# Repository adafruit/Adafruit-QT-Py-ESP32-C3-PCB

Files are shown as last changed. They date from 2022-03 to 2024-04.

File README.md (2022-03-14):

## Adafruit QT Py ESP32-C3 WiFi Dev Board with STEMMA QT PCB

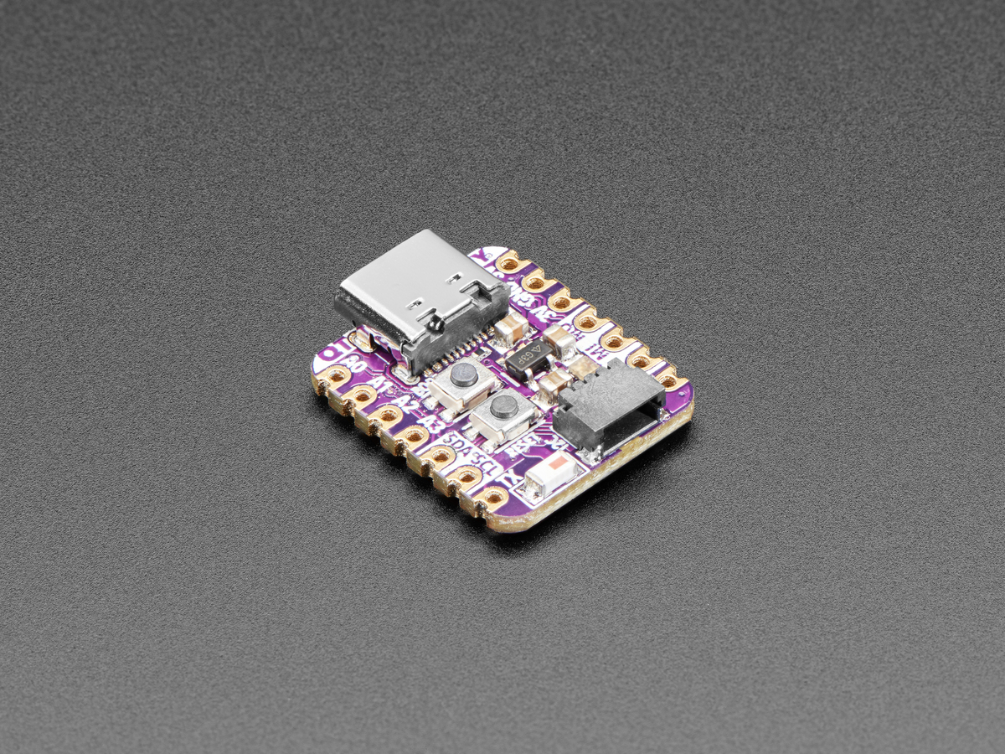
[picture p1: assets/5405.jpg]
<a href="http://www.adafruit.com/products/5405"><br/>
Click here to purchase one from the Adafruit shop</a>

PCB files for the Adafruit QT Py ESP32-C3 WiFi Dev Board with STEMMA QT. 

Format is EagleCAD schematic and board layout
* https://www.adafruit.com/product/5405

### Description

What's life without a little RISC? This miniature dev board is perfect for small projects: it comes with our favorite connector - the STEMMA QT, a chainable I2C port, WiFi, Bluetooth LE, and plenty of FLASH and RAM memory for many IoT projects. What a cutie pie! Or is it... a QT Py? This diminutive dev board comes with a RISC-V IoT microcontroller, the ESP32-C3!

ESP32-C3 is a low-cost microcontroller from Espressif that supports 2.4 GHz Wi-Fi and Bluetooth® Low Energy (Bluetooth LE). It has built-in USB-to-Serial, but not native USB - it cannot act as a keyboard or disk drive. The chip used here has 4MB of Flash memory, 400 KB of SRAM and can easily handle TLS connections.

The ESP32-C3 integrates a rich set of peripherals, ranging from UART, I2C, I2S, remote control peripheral, LED PWM controller, general DMA controller, TWAI controller, USB Serial/JTAG controller, temperature sensor, and ADC. It also includes SPI, Dual SPI, and Quad SPI interfaces. There is no DAC or native capacitive touch.

There's a minimum number of pins on this chip, it's specifically designed to be low cost and for simpler projects than ESP32-Sx or ESP32 classics with their large number of GPIO. Think of it more as an intended replacement to the ESP8266 than to the ESP32!

With its state-of-the-art power and RF performance, this SoC is an ideal choice for a wide variety of application scenarios relating to the Internet of Things (IoT), wearable electronics, and smart homes.

### License

Adafruit invests time and resources providing this open source design, please support Adafruit and open-source hardware by purchasing products from [Adafruit](https://www.adafruit.com)!

Designed by Limor Fried/Ladyada for Adafruit Industries.

Creative Commons Attribution/Share-Alike, all text above must be included in any redistribution. 
See license.txt for additional details.

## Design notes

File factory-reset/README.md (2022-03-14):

## Factory Reset file - QT Py ESP32-C3 WiFi Dev Board with STEMMA QT

This is the factory reset file for the QT Py ESP32-C3 WiFi Dev Board with STEMMA QT.

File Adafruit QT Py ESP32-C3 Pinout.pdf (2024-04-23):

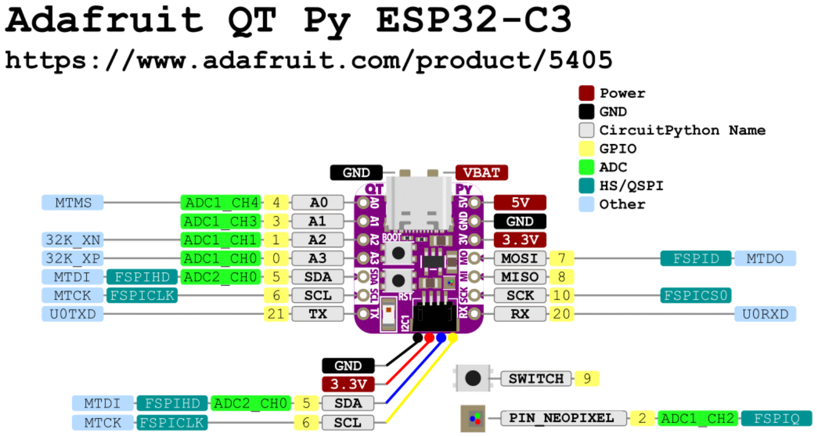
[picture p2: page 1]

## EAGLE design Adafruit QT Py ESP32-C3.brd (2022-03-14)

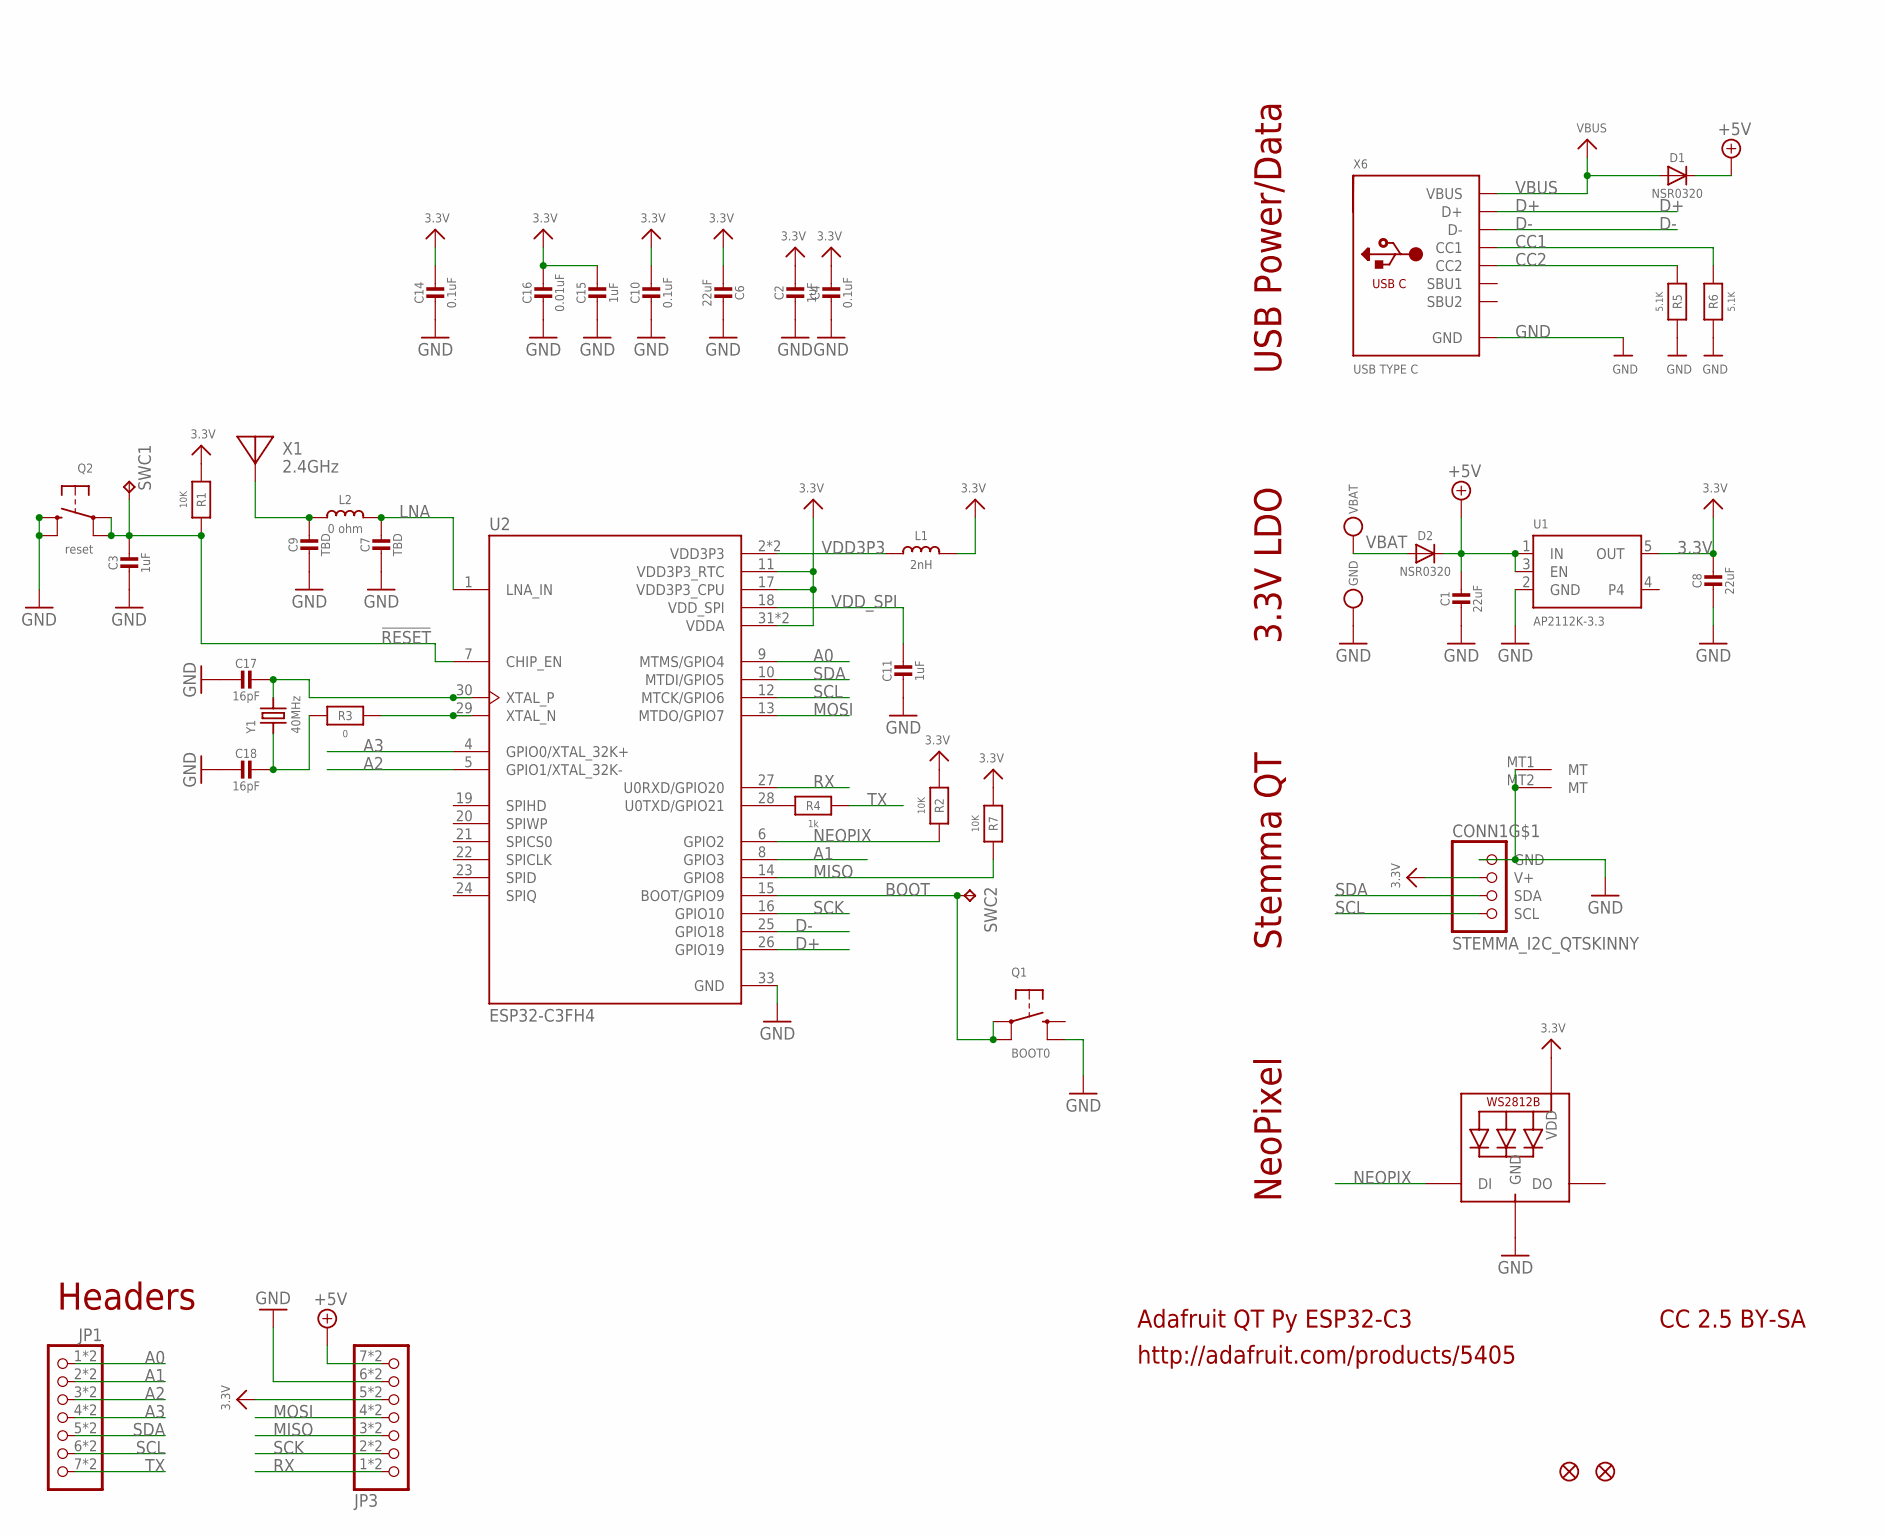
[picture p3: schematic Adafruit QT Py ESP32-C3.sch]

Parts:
C1, C6, C8: 22uF; 0805-NO
C2, C3, C11, C15: 1uF; _0402NO
C4, C10, C14: 0.1uF; _0402NO
C7, C9: TBD; _0402NO
C16: 0.01uF; _0402NO
C17, C18: 16pF; _0402NO
CONN1: STEMMA_I2C_QTSKINNY; JST_SH4_SKINNY
D1, D2: NSR0320; SOD-323_MINI
GND: TESTPOINT_MINUS; TESTPOINT_MINUS_1X3MM
JP1, JP3: HEADER-1X7_CASTEL; 1X07_CASTEL
L1: 2nH; _0402
L2: 0 ohm; _0402
LED1: WS2812B_SK6805_1515; SK6805_1515
Q1: BOOT0; BTN_KMR2_4.6X2.8
Q2: reset; BTN_KMR2_SLIM
R1, R2: 10K; _0402NO
R3: 0; _0402NO
R4: 1k; _0402NO
R5, R6: 5.1K; _0402NO
R7: 10K; _0603MP_TWO6MIL
SWC1, SWC2: TPB1,27; B1,27
U1: AP2112K-3.3; SOT23-5
U2: ESP32-C3FH4; QFN32_5MM
U$6, U$8: FIDUCIAL_1MM
VBAT: TESTPOINT_PLUS13; TESTPOINT_PLUS_1X3MM
X1: 2.4GHz; ANT_2450AT18B100
X6: USB TYPE C; USB_C_CUSB31-CFM2AX-01-X
Y1: 40MHz; CRYSTAL_2X1.6

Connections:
3.3V: C2.1, C4.1, C6.1, C8.1, C10.1, C14.1, C15.1, C16.1, CONN1.2 (V+), JP3.5, JP3.5C (5), L1.1, LED1.2 (VDD), R1.1, R2.1, R7.1, U1.5 (OUT), U2.11 (VDD3P3_RTC), U2.17 (VDD3P3_CPU), U2.31 (VDDA), U2.32 (VDDA)
!RESET: C3.1, Q2.A, Q2.A' (P1), R1.2, SWC1.TP, U2.7 (CHIP_EN)
+5V: C1.1, D1.C, D2.C, JP3.7, JP3.7C (7), U1.1 (IN), U1.3 (EN)
A0: JP1.1, JP1.1C (1), U2.9 (MTMS/GPIO4)
A1: JP1.2, JP1.2C (2), U2.8 (GPIO3)
A2: JP1.3, JP1.3C (3), U2.5 (GPIO1/XTAL_32K-)
A3: JP1.4, JP1.4C (4), U2.4 (GPIO0/XTAL_32K+)
BOOT: Q1.A, Q1.A' (P1), SWC2.TP, U2.15 (BOOT/GPIO9)
CC1: R6.2, X6.A5 (CC1)
CC2: R5.2, X6.B5 (CC2)
D+: U2.26 (GPIO19), X6.A6 (D+), X6.B6 (D+)
D-: U2.25 (GPIO18), X6.A7 (D-), X6.B7 (D-)
GND: C1.2, C2.2, C3.2, C4.2, C6.2, C7.2, C8.2, C9.2, C10.2, C11.2, C14.2, C15.2, C16.2, C17.2, C18.2, CONN1.1 (GND), CONN1.MT1 (MT), CONN1.MT2 (MT), GND.P$1, JP3.6, JP3.6C (6), LED1.4 (GND), Q1.B' (S1), Q2.B (S), Q2.B' (S1), R5.1, R6.1, U1.2 (GND), U2.33 (GND), X6.A1B12 (GND), X6.B1A12 (GND)
LNA: C7.1, L2.2, U2.1 (LNA_IN)
MISO: JP3.3, JP3.3C (3), R7.2, U2.14 (GPIO8)
MOSI: JP3.4, JP3.4C (4), U2.13 (MTDO/GPIO7)
unnamed: R4.1, U2.28 (U0TXD/GPIO21)
unnamed: C9.1, L2.1, X1.FP
unnamed: R3.2, U2.29 (XTAL_N)
unnamed: C17.1, U2.30 (XTAL_P), Y1.3 (2)
unnamed: C18.1, R3.1, Y1.1
NEOPIX: LED1.1 (DI), R2.2, U2.6 (GPIO2)
RX: JP3.1, JP3.1C (1), U2.27 (U0RXD/GPIO20)
SCK: JP3.2, JP3.2C (2), U2.16 (GPIO10)
SCL: CONN1.4 (SCL), JP1.6, JP1.6C (6), U2.12 (MTCK/GPIO6)
SDA: CONN1.3 (SDA), JP1.5, JP1.5C (5), U2.10 (MTDI/GPIO5)
TX: JP1.7, JP1.7C (7), R4.2
VBAT: D2.A, VBAT.P$1
VBUS: D1.A, X6.A4B9 (VBUS), X6.B4A9 (VBUS)
VDD3P3: L1.2, U2.2 (VDD3P3), U2.3 (VDD3P3)
VDD_SPI: C11.1, U2.18 (VDD_SPI)

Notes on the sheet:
Adafruit QT Py ESP32-C3
http://adafruit.com/products/5405
CC 2.5 BY-SA
NeoPixel
Stemma QT
3.3V LDO
USB Power/Data
Headers

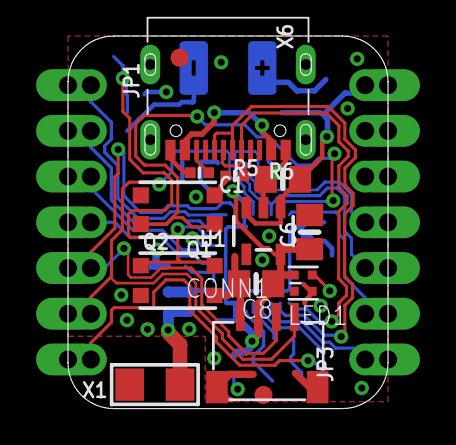
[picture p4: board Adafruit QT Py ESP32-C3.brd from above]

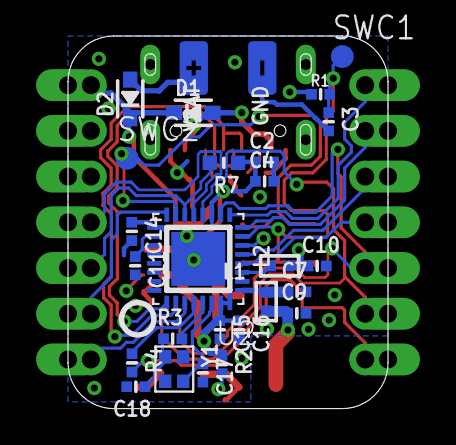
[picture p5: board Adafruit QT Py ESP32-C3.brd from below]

Board: 2 copper layers, 17.8 x 20.7 mm, 46 parts (29 on the bottom side), 31 nets.

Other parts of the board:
U$3: QTPYC3_TOP
U$12: PCBFEAT-REV-040
U$18: QTPYC3_BOT

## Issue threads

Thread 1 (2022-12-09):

Add pdf of schematic

Teslafly, 2022-12-09:
Can a pdf if the schematic be added so one doesn't have to have eagle installed to view it?

tannewt, 2022-12-12:
Images of the schematic are available in product learn guides: https://learn.adafruit.com/adafruit-qt-py-esp32-c3-wifi-dev-board/downloads#schematic-and-fab-print-3113127

I've also used KiCad to view the files without trouble.

Closed 2022-12-12.

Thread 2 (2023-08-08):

XTAL part number?

TechOverflow, 2023-08-08:
Hi!
Just wondering which crystal is used on this board as there is no bom.

Thanks!

ladyada, 2023-08-09:
ECS ECS-400-10-37B2-CKM-TR

Closed 2023-08-09.

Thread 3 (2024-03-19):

Add Power Domain/RTC pins to pinout PDF (similar to S3 variant)

jprouty, 2024-03-19:
Please add a "Power Domain" label to the [C3 pinout PDF](https://github.com/adafruit/Adafruit-QT-Py-ESP32-C3-PCB/blob/main/Adafruit%20QT%20Py%20ESP32-C3%20Pinout.pdf), similar to the [pinout diagram for the S3](https://github.com/adafruit/Adafruit-QT-Py-ESP32-S3-PCB/blob/main/Adafruit_QT_Py_ESP32-S3_Pinout.pdf).

It took me a few minutes to cross reference nomenclature to figure out what I needed via resources like espressif's [GPIO summary](https://docs.espressif.com/projects/esp-idf/en/stable/esp32c3/api-reference/peripherals/gpio.html).

tannewt, 2024-03-19:
:wave: Looks like @BlitzCityDIY added that to the S3 diagram. She may know how to do it for this.

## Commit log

2022-03-14 Initial commit - added pcb files
    [Adafruit QT Py ESP32-C3.brd, Adafruit QT Py ESP32-C3.sch]
2024-04-23 Correct the NeoPixel Arduino name

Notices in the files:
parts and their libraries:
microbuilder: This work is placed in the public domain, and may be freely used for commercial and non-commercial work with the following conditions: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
